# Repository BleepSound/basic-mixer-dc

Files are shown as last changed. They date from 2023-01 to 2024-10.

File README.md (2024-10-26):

# basic DC mixer

Basic DC mixer with 4 ins and one out.

DC coupled, can work with both audio and CV.

Mute switches and vol pots on all voices.

One main out and one inverted out.

You'll find the schematic of this module below:

basic dc Mixer schematic

Regular build, I use ceramic capacitors but you can use film/polyester.

:warning: When building modules, always do it in this order (from smallest component to highest):
- diodes
- resistors
- DIP chips
- capacitors (film/ceramic)
- Electrolytic capacitors

For the next part, always place them without soldering them on:
- jacks, pots and switches that go thought the front panel

Once placed, put in place the front panel, then fasten all components to it. Once this is done, you can solder them.

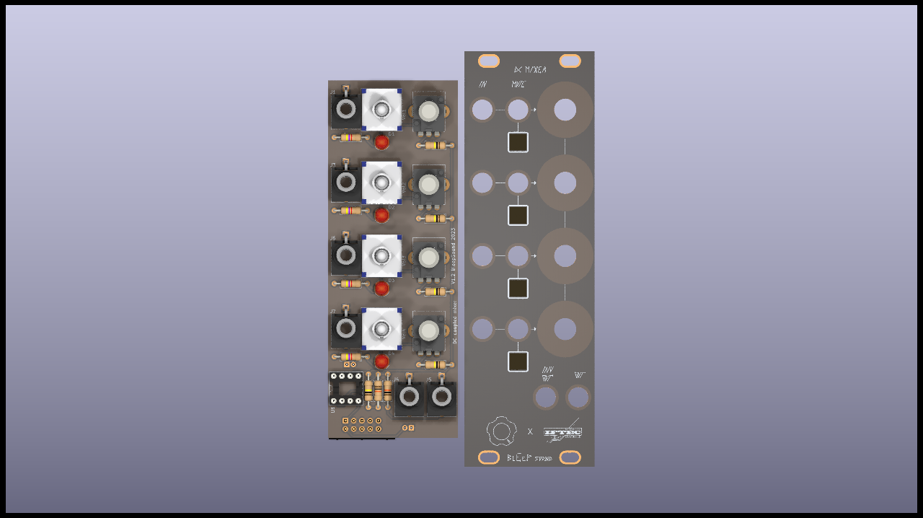
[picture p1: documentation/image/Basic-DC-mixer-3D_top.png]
3D Basic-DC-mixer(front)


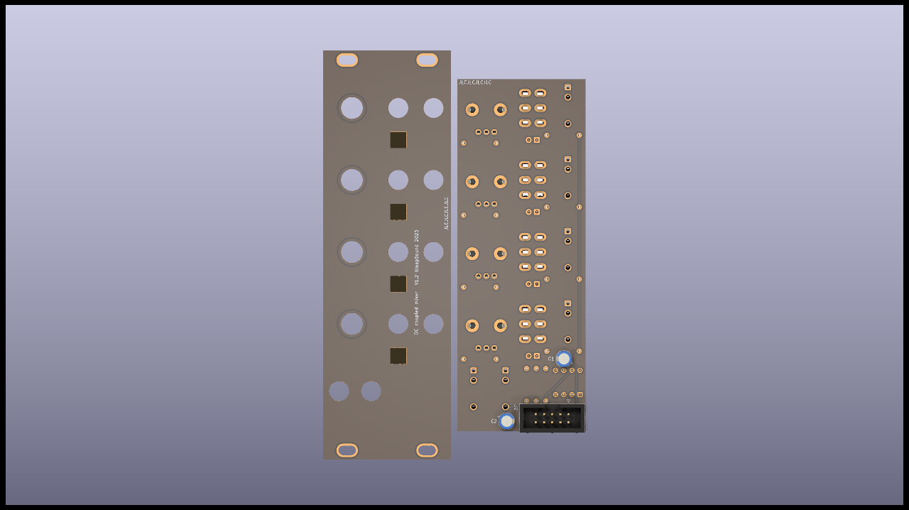
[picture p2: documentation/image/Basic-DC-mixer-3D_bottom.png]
3D Basic-DC-mixer(back)


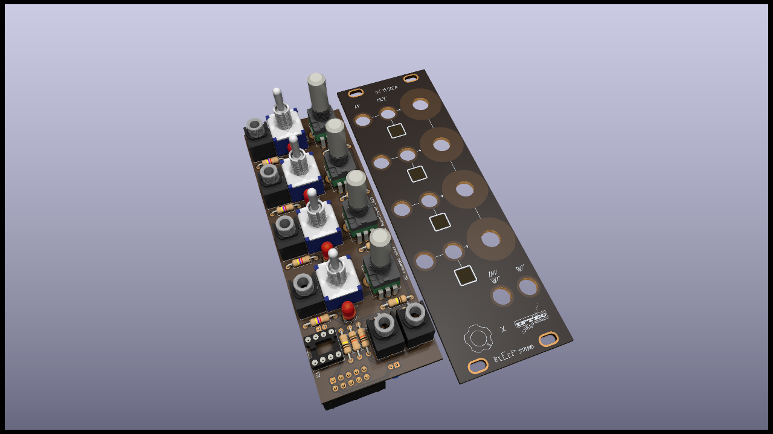
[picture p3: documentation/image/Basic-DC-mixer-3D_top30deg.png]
3D Basic-DC-mixer(iso)


[See bom globale](documentation/bom/Basic-DC-mixer-ibom-global.html)

[See bom board jack](documentation/bom/Basic-DC-mixer-ibom-jack.html)

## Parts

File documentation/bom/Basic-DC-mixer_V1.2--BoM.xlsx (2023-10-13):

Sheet: BoM
Basic-DC-mixer_V1.2 Bill of Materials
Schematic: | Basic-DC-mixer | Component Groups: | 12
Variant: | default | Component Count: | 33 (0 SMD/ 33 THT)
Revision: | 1.2 | Fitted Components: | 33 (0 SMD/ 33 THT)
Date: | 2023-10-13 | Number of PCBs: | 1
KiCad Version: | 7.0.7-7.0.7~ubuntu22.04.1 | Total Components: | 33
Row | Description | References | Value | Quantity Per PCB | Comments
1 |  | C1 C2 | 10µ | 2
2 | Light emitting diode | D1 D2 D3 D4 | LED-mute | 4
3 | Thonkiconn Audio Jack | J1 J3 J6 J7 | In | 4 | Thonkiconn jack
4 | Thonkiconn Audio Jack | J4 | InvOut | 1 | Thonkiconn jack
5 | Thonkiconn Audio Jack | J5 | Out | 1 | Thonkiconn jack
6 | Generic connector, single row, 01x10, script generated (kicad-library-utils/schlib/autogen/connector/) | J2 | Power Input | 1
7 | Resistor | R1 R3 R5 R10 | 4.7k | 4
8 | Resistor | R6 R7 | 10k | 2
9 | Resistor | R2 R4 R8 R9 R11 | 100k | 5
10 | Momentary Switch, dual pole double throw | SW1 SW2 SW3 SW4 | Mute (https://www.taydaelectronics.com/mini-toggle-switch-dpdt-on-on.html) | 4 | DPDT On-ON
11 | Dual Low-Noise JFET-Input Operational Amplifiers, DIP-8/SOIC-8 | U1 | TL072 (http://www.ti.com/lit/ds/symlink/tl071.pdf) | 1
12 |  | Vol1 Vol2 Vol3 Vol4 | 10k | 4

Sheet: Colors
KiCad Fields (default)
Generated Fields
User Fields
Empty Fields

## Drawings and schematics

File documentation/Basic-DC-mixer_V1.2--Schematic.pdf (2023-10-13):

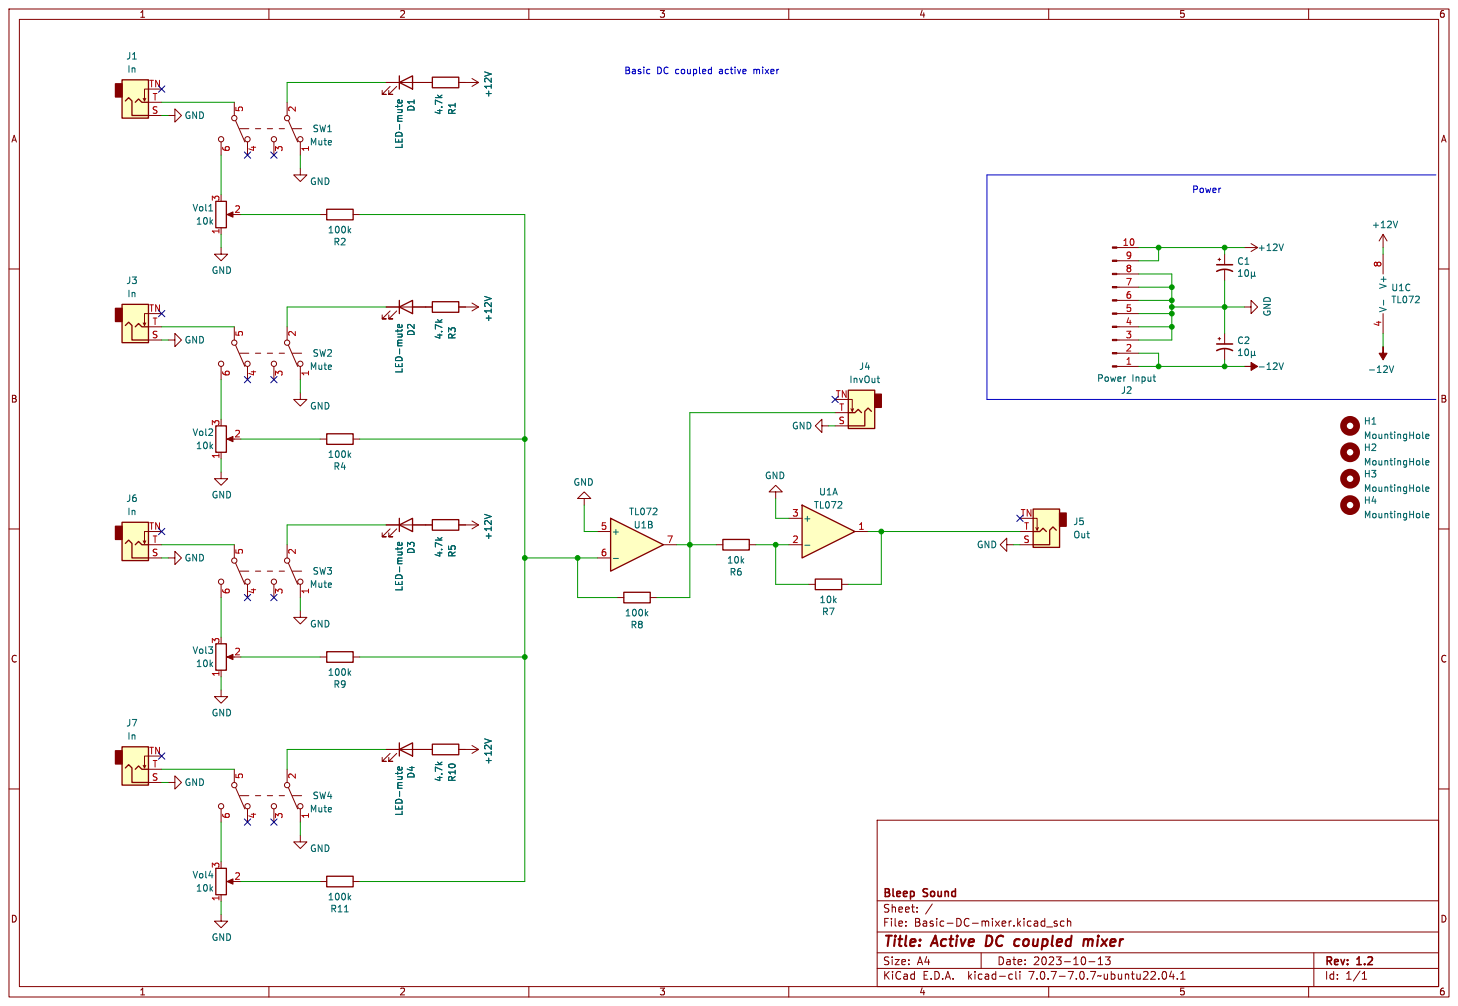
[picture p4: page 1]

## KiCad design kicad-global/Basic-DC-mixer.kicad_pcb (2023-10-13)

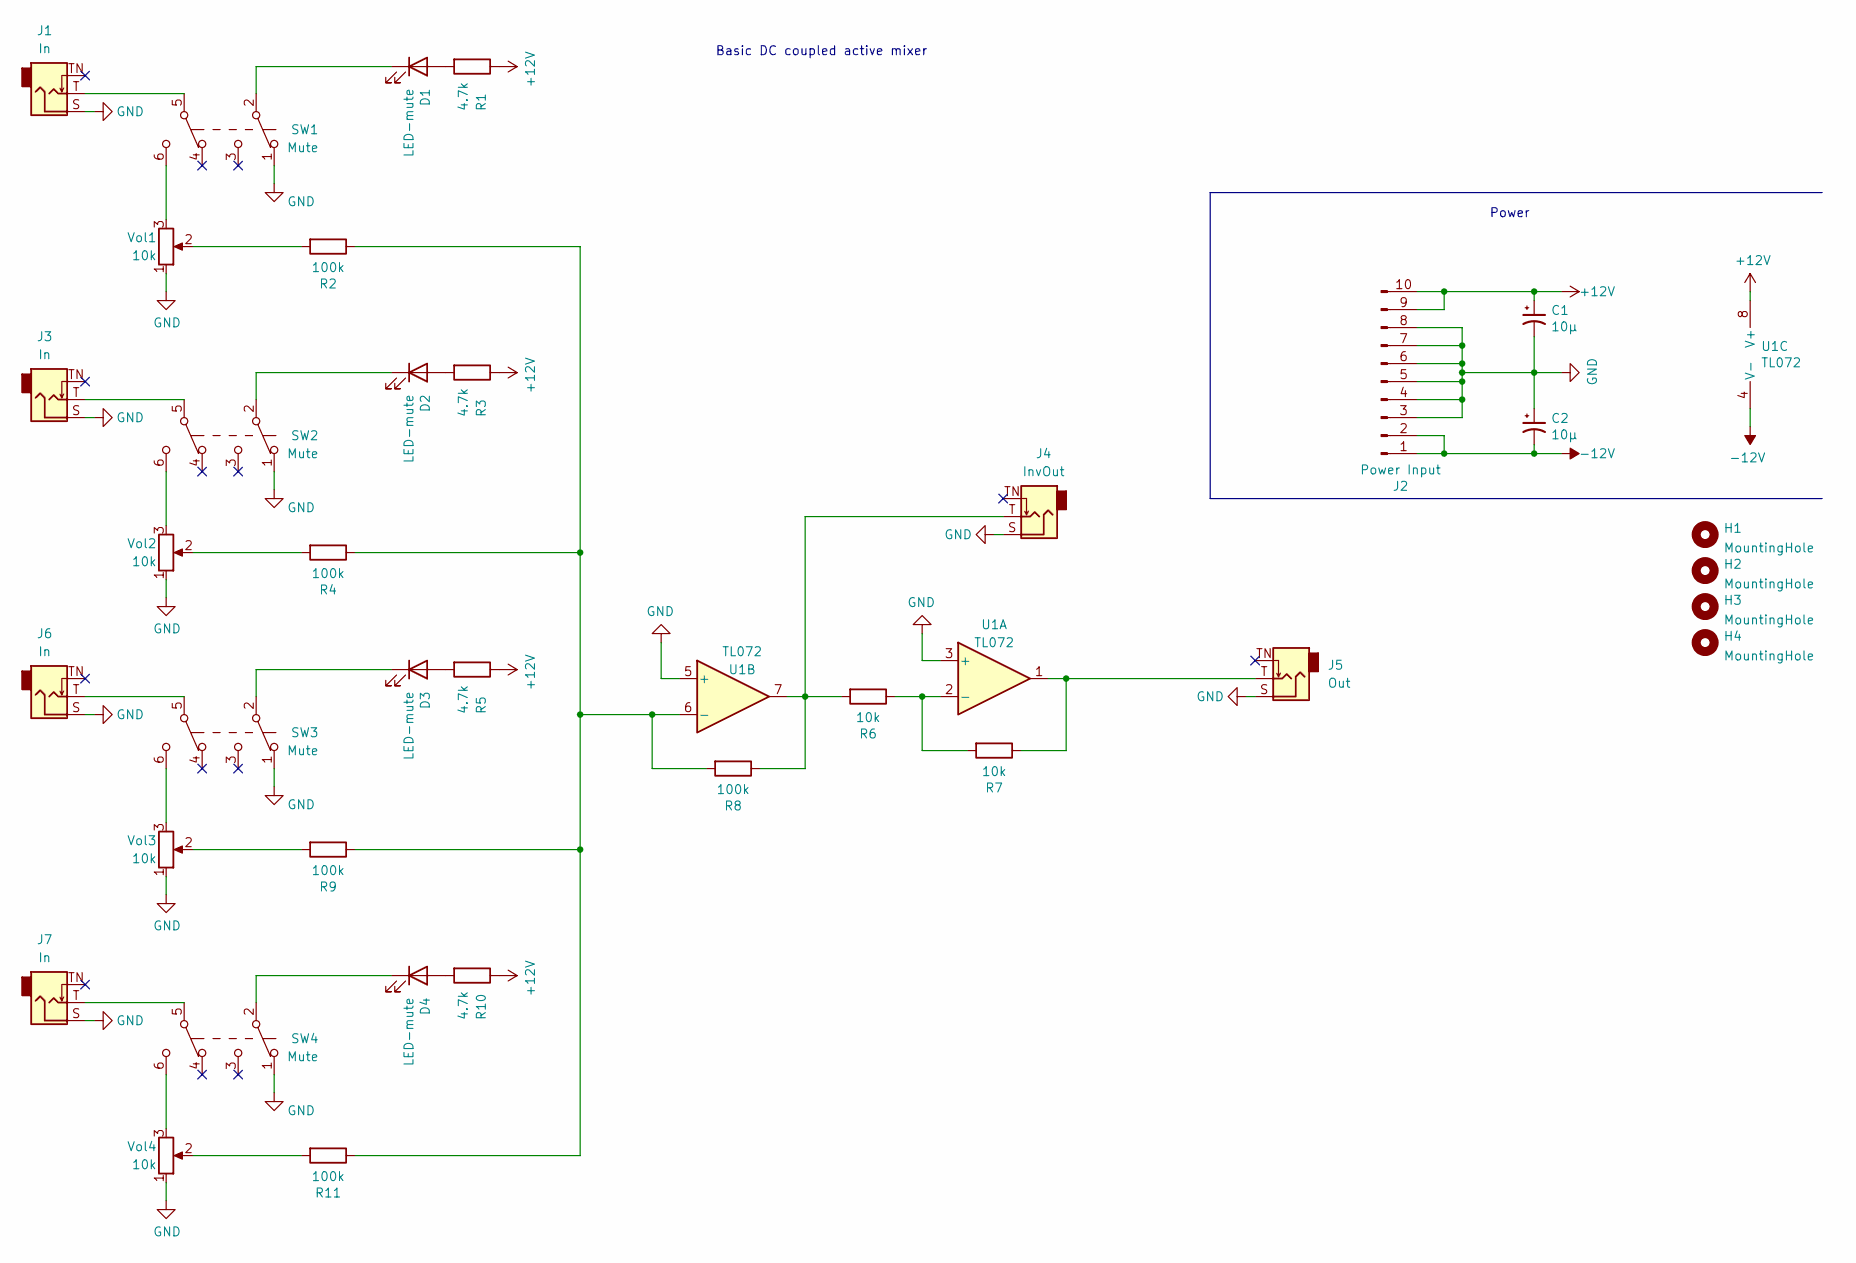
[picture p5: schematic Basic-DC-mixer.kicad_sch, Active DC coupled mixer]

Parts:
C1, C2: 10µ; CP_Radial_D5.0mm_P2.00mm
D1, D2, D3, D4: LED-mute; LED_D4.0mm
H1, H2, H3, H4: MountingHole; Doepfer Mounting hole
J1, J3, J6, J7: In; Thonkiconn
J2: Power Input; IDC-Header_2x05_P2.54mm_Vertical
J4: InvOut; Thonkiconn
J5: Out; Thonkiconn
R1, R3, R5, R10: 4.7k; R_Axial_DIN0207_L6.3mm_D2.5mm_P10.16mm_Horizontal
R2, R4, R8, R9, R11: 100k; R_Axial_DIN0207_L6.3mm_D2.5mm_P10.16mm_Horizontal
R6, R7: 10k; R_Axial_DIN0207_L6.3mm_D2.5mm_P10.16mm_Horizontal
SW1, SW2, SW3, SW4: Mute; SW_DPDT_Toggle
U1: TL072; DIP-8_W7.62mm_Socket
Vol1, Vol2, Vol3, Vol4: 10k; Pot-bourns-alpha

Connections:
+12V: C1.1, J2.9, J2.10, R1.1, R3.1, R5.1, R10.1, U1.8 (V+)
-12V: C2.2, J2.1, J2.2, U1.4 (V-)
GND: C1.2, C2.1, J1.S, J2.3, J2.4, J2.5, J2.6, J2.7, J2.8, J3.S, J4.S, J5.S, J6.S, J7.S, SW1.1 (A), SW2.1 (A), SW3.1 (A), SW4.1 (A), U1.3 (+), U1.5 (+), Vol1.1, Vol2.1, Vol3.1, Vol4.1
unnamed: D1.2 (A), R1.2
unnamed: D1.1 (K), SW1.2 (B)
unnamed: D2.2 (A), R3.2
unnamed: D2.1 (K), SW2.2 (B)
unnamed: D3.2 (A), R5.2
unnamed: D3.1 (K), SW3.2 (B)
unnamed: D4.2 (A), R10.2
unnamed: D4.1 (K), SW4.2 (B)
unnamed: J1.T, SW1.5 (B)
unnamed: J3.T, SW2.5 (B)
unnamed: J4.T, R6.2, R8.1, U1.7
unnamed: J5.T, R7.1, U1.1
unnamed: J6.T, SW3.5 (B)
unnamed: J7.T, SW4.5 (B)
unnamed: R2.2, Vol1.2
unnamed: R4.2, Vol2.2
unnamed: R9.2, Vol3.2
unnamed: R11.2, Vol4.2
unnamed: SW1.6 (C), Vol1.3
unnamed: SW2.6 (C), Vol2.3
unnamed: SW3.6 (C), Vol3.3
unnamed: SW4.6 (C), Vol4.3
unnamed: R6.1, R7.2, U1.2 (-)
unnamed: R2.1, R4.1, R8.2, R9.1, R11.1, U1.6 (-)

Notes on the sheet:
Power
Basic DC coupled active mixer

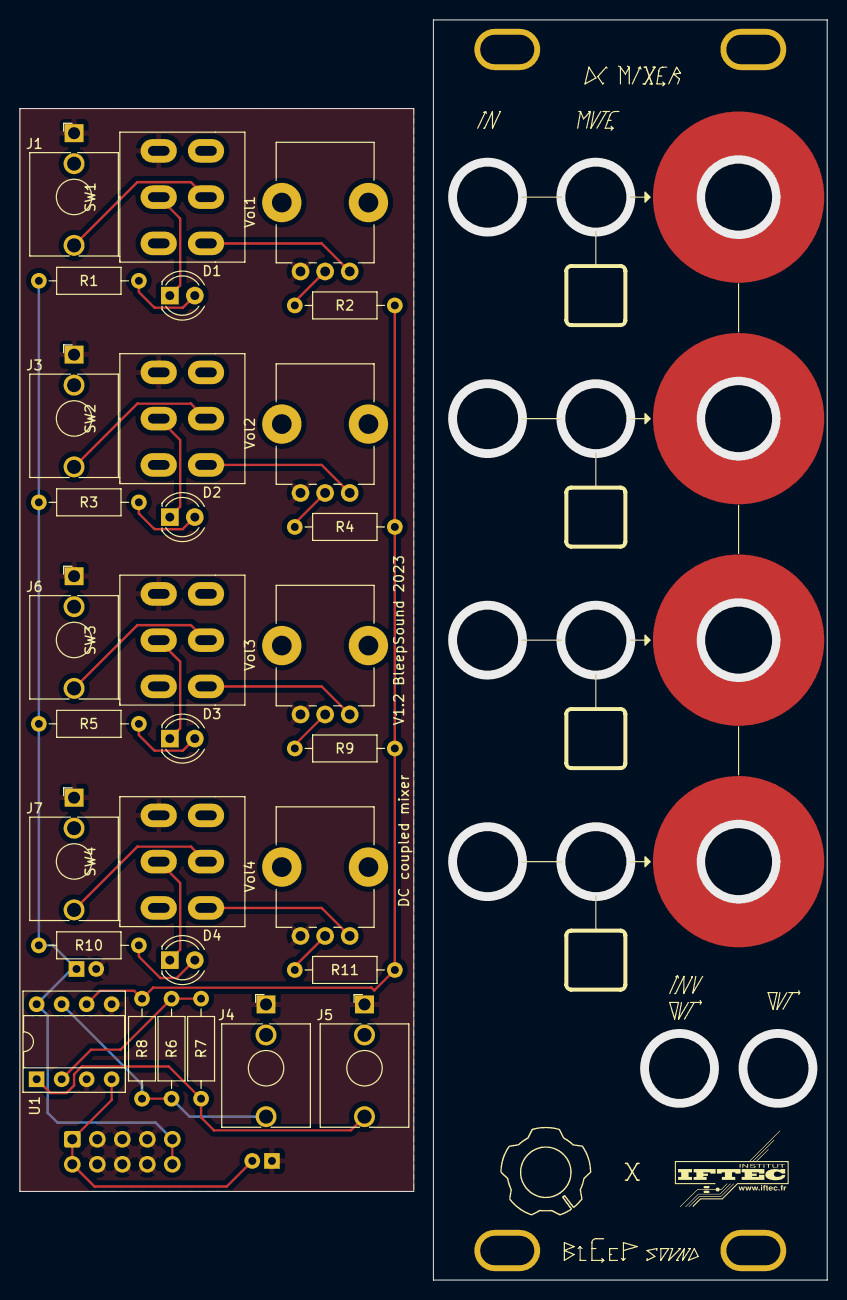
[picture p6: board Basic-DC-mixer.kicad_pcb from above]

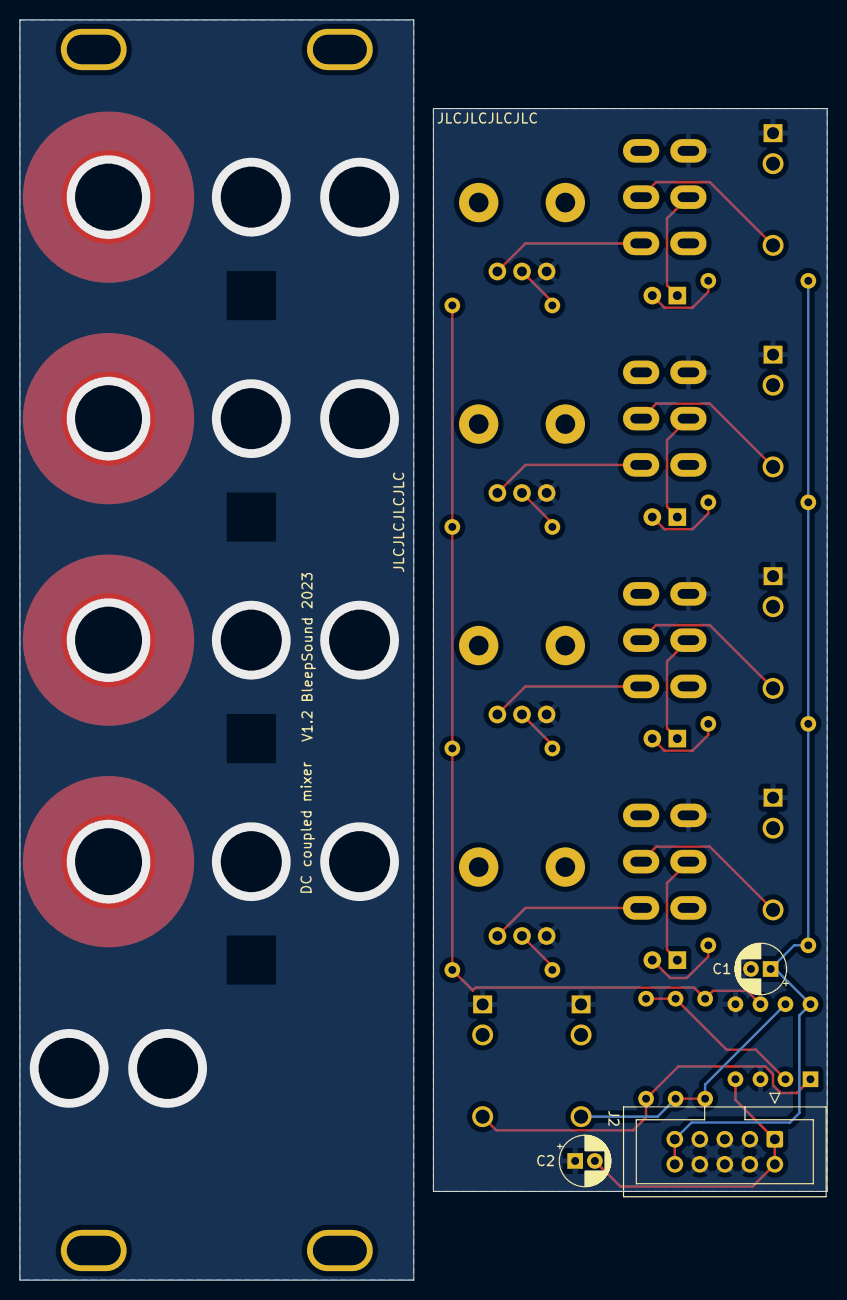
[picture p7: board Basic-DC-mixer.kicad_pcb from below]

Board: 2 copper layers, 82.0 x 128.0 mm, 37 parts (3 on the bottom side), 27 nets.

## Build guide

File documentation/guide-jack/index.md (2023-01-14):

# Populate Manual for MS20-VCF

Follow this manual to populate the PCB: 

The basic rule is, always go from the smallest to the highest component on the board !

####  This is the front side of the board we are populating

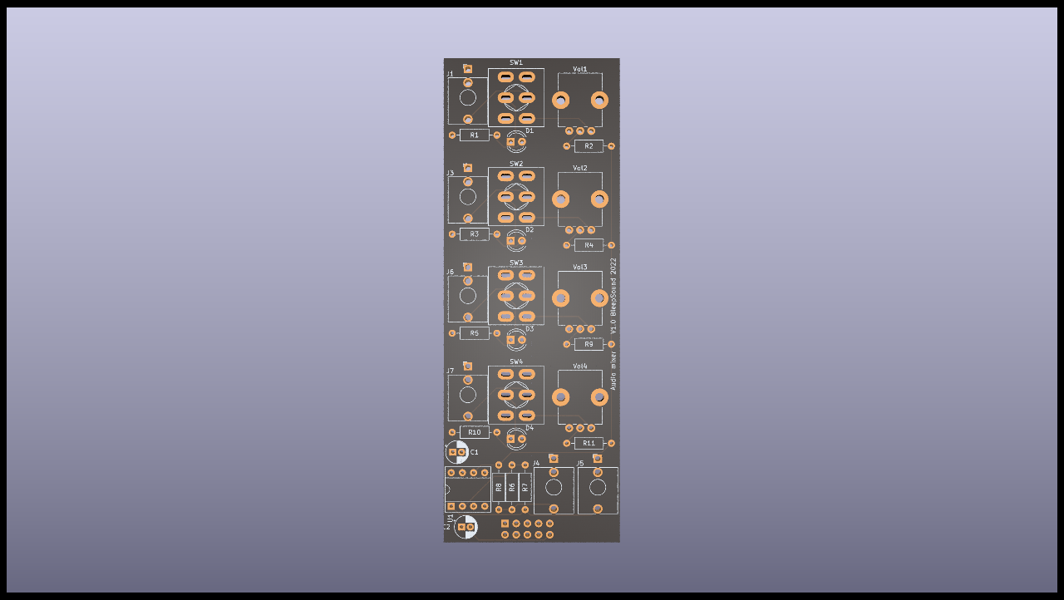
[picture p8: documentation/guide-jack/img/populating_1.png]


 This is the back side of the board we are populating.

####  This is the back side of the board we are populating.

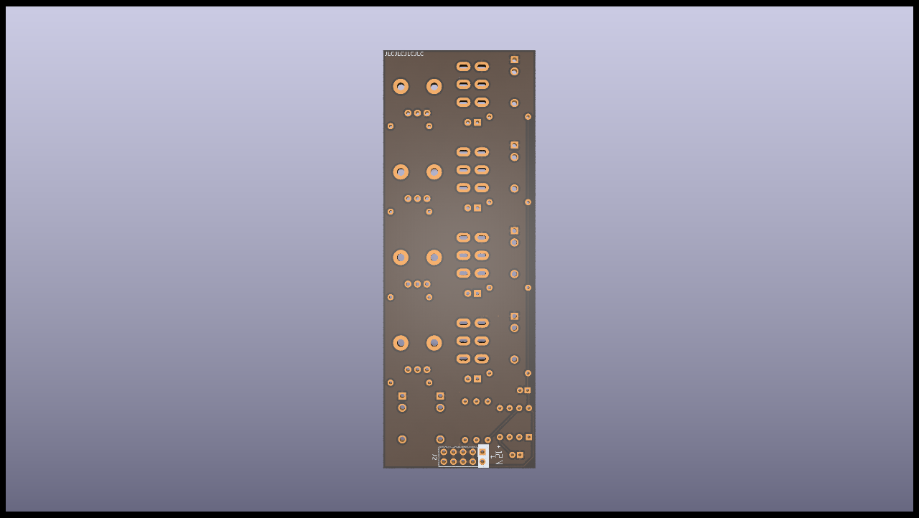
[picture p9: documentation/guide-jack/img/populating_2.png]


 You can start by all the resistors (by value so you don't make mistakes)

####  You can start by all the resistors (by value so you don't make mistakes)

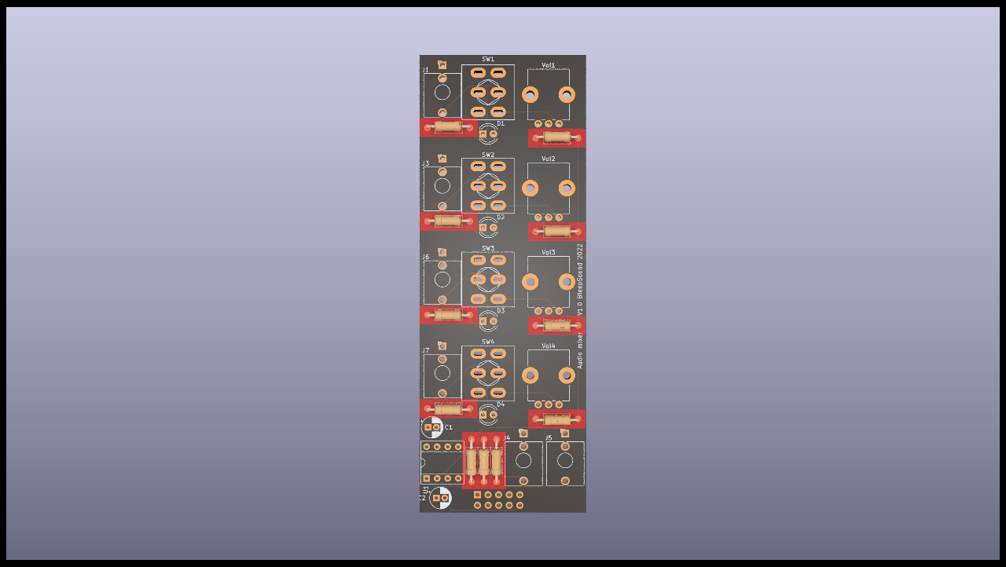
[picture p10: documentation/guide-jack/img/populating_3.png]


####  Add the socket for the TL072, making sure you get the orientation right. Don't add the Tl072 yet, you'll add it at the end. 

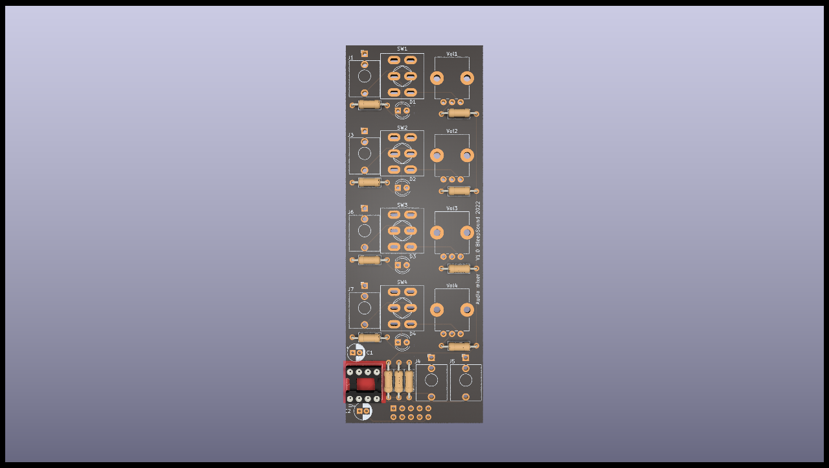
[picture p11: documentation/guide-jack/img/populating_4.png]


####  Add the electrolytic capacitors.

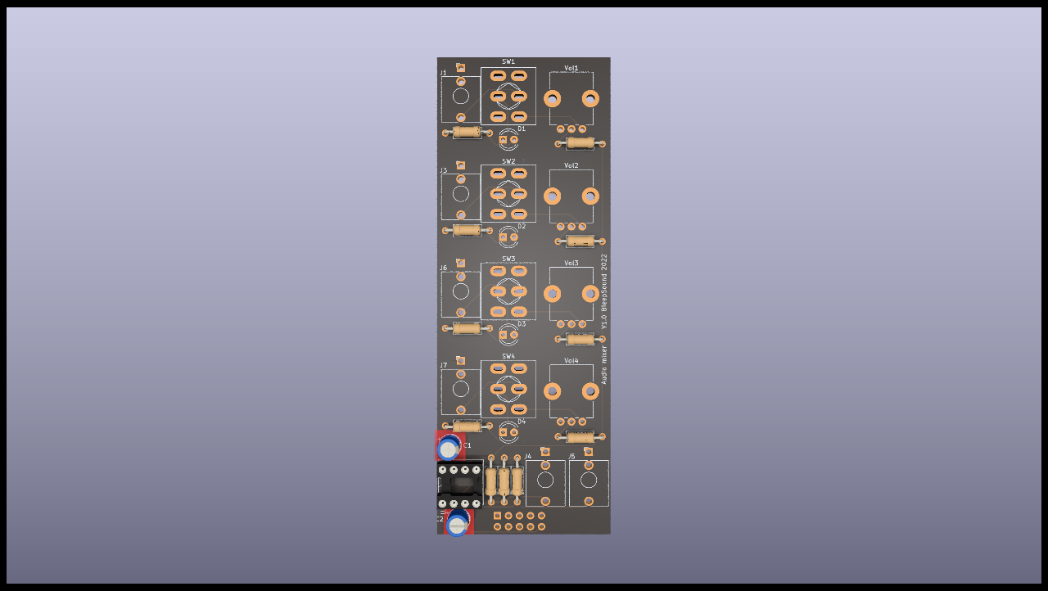
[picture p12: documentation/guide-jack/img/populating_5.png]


The last step concern the jacks, potentiometers, LEDs and switches. Basically, anything that is accessible throught the front panel. You first place them.

:warning: DO NOT SOLDER THEM YET :warning:

(this is really important !!)

####  Do Not Solder Them! place them first and put the front panel in place. You'll be able to put the" knobs of your choice on those.

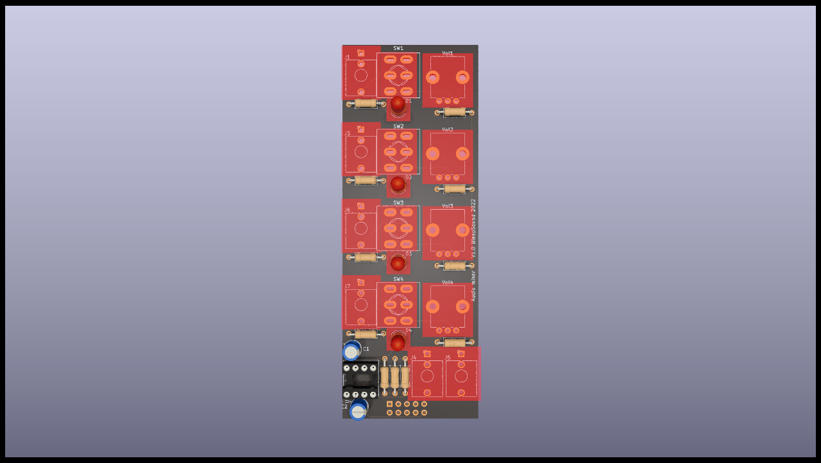
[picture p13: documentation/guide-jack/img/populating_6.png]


You can place the TL0&" in place before you put the front panel on.

You then put in place the front panel, making sure everything fits. Once all the jack sockets and switches are fastenned to the front panel, you can solder them, and only then !!!

The front is done, we can flip the PCB and start the back !

####  Add the power header and that's it !

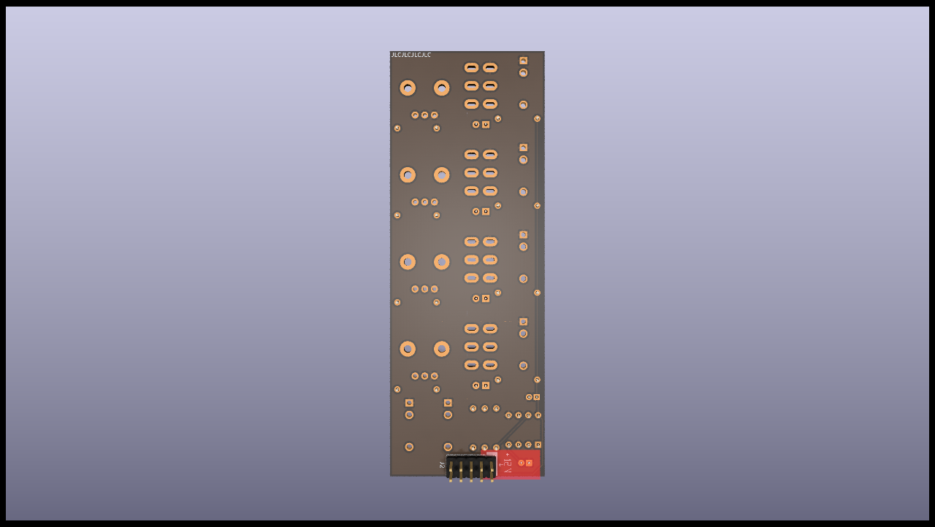
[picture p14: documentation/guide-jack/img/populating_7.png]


## Conclusion

This is the end of the build, if yoy have any questions, don't hesitate !

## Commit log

2023-01-12 add jack gerber
    [Basic-DC-mixer--NPTH_map.gbr, Basic-DC-mixer--PTH_map.gbr, Basic-DC-mixer-B_Cu.gbl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]
2023-01-12 add main BoM and images
    [Basic-DC-mixer-bom.xlsx]
2023-01-12 add front gerber
    [Basic-DC-mixer--NPTH_map.gbr, Basic-DC-mixer--PTH_map.gbr, Basic-DC-mixer-B_Cu.gbl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]
2023-01-12 add jack BoM
2023-06-10 update silkscreen and hole diameter
    [Basic-DC-mixer.kicad_pcb, Basic-DC-mixer.kicad_sch]
2023-10-13 update mixer to v1.2, update repo organization
    [Basic-DC-mixer--NPTH_map.gbr, Basic-DC-mixer--PTH_map.gbr, Basic-DC-mixer-B_Cu.gbl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]
